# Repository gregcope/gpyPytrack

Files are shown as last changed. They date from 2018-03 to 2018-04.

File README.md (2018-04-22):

gpyPytrack
=========

Intro
==========
Based on a Pycom gpy (Bluetooth, WLAN, LTE) ESP32 MicroPython board and its associated Pytrack module that has a L76 GNSS module (and LIPO battery charger).  This project needs a Daughter board.

Aim
==========
* Be very, very low power (17uA when asleep with GNSS VBACKUP powered)
* Chargeable from 12-24V
* Rechargeable LIPO battery for easy parts sourcing
* Has a button to enable user wake up
* GNSS For location
* LTE for Coms
* BilgeSwitch and Temp (DS18B20) Alarms
* LED for Status (in switch)

Checks
=============
* Frequent
  * BilgeSwitch state
  * Temp above / below threshold
  * If in Alarm, send coms
* Less Frequent (less likely to change frequently)
  * Position
  * Battery volts
  * VCC volts
  * If in Alarm, send coms
* Daily
  * All of the above and sends status

Parts
==========
* [Pycom Gpy](https://pycom.io/hardware/gpy-specs)
* [Pycom pytrack](https://pycom.io/hardware/pytrack-specs/)
* [Mini Step Down Regulator Voltag Power Supply Module 4.5v~55v to 5v](https://www.ebay.co.uk/sch/i.html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)
* [DS18B20 Waterproof Digital Probe Temperature Sensor with Silicone Cable (higher temp) Thermometer](https://www.ebay.co.uk/sch/i.html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)
* [12V 12mm LED Power Push Button Switch Momentary Waterproof Metal 4 Pin](https://www.ebay.co.uk/sch/i.html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)
* 1200mah LIPO Battery
* Bilge Switch (any normally closed, simple switch would do)

Daughter board
==============
The Daughter board fits between the Gpy/Fipy and Pytrack module via headers (see pictures when I add them).  It is designed to hold certain parts and expose some pins via headers or JST connectors.   Its footprint is similar to the Pytrack to keep space requirements down.

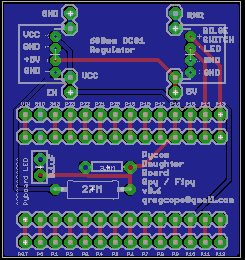
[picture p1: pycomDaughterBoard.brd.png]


The Daughter board mounts;
* VCC voltagedivider connected to an ADC pin to measure VCC
* Switchable Regulator with ENABLE pin connected to a pin
* JST(s) to breakout the relevant connections for the 11-36v VCC+GND, LED, Switch, DS18B20 Temp module, BilgeSwitch, 5V+GND for the Pytrack USB port
* __Note we will be putting 2x5pin XH JSTs on the Pytrack External IO to use those as well (simplifies this board and makes it smaller)__  

See the eagle files for the details.

Referances
=============
* https://blog.yavilevich.com/2017/03/efficient-dc-12v-to-5v-conversion-for-low-power-electronics-evaluation-of-six-modules/

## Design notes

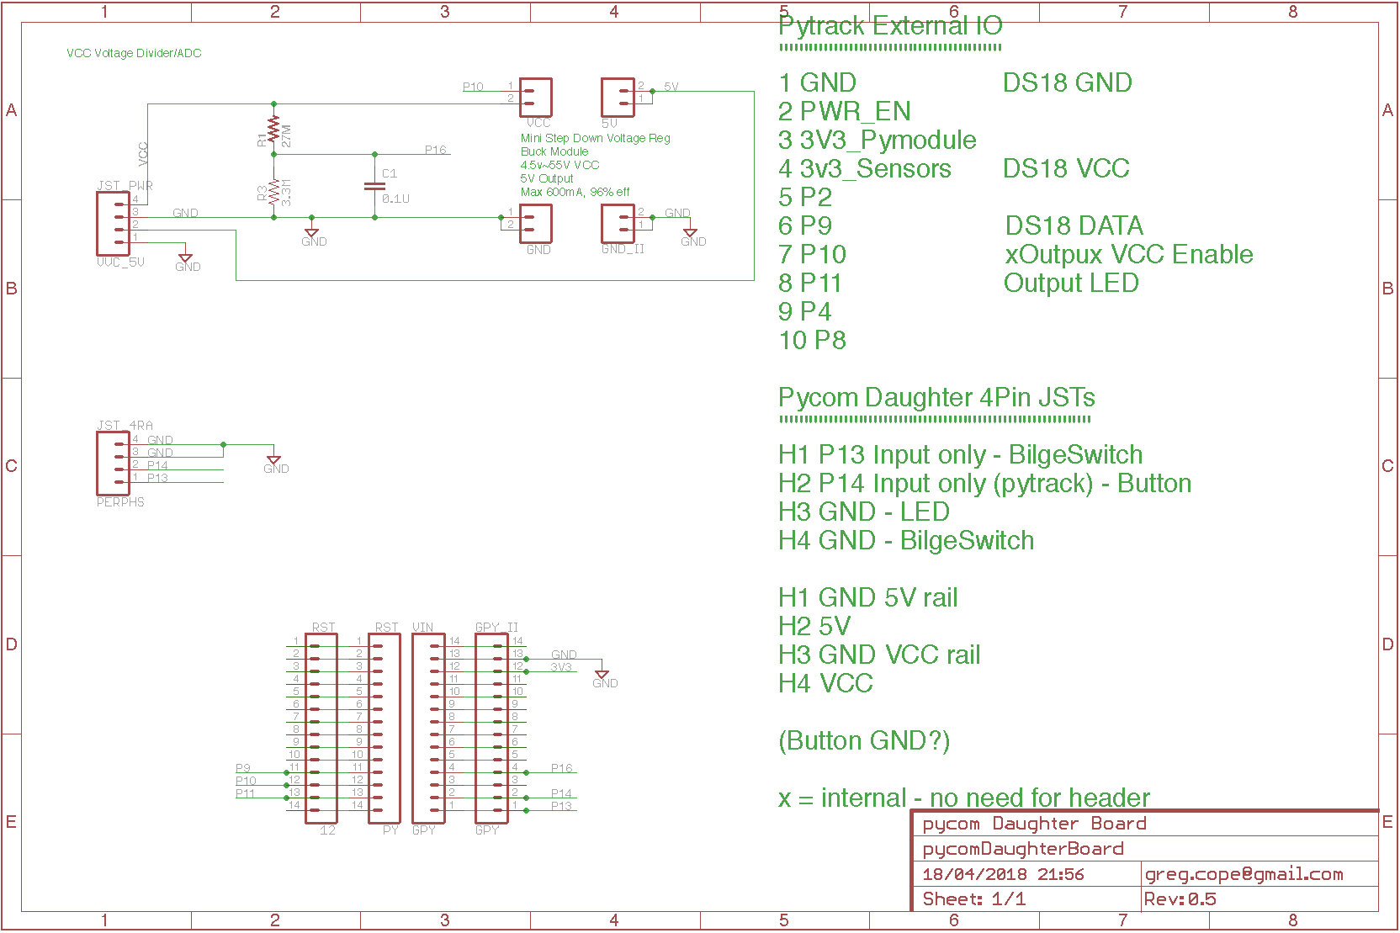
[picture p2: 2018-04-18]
pycomDaughterBoard.sch.png

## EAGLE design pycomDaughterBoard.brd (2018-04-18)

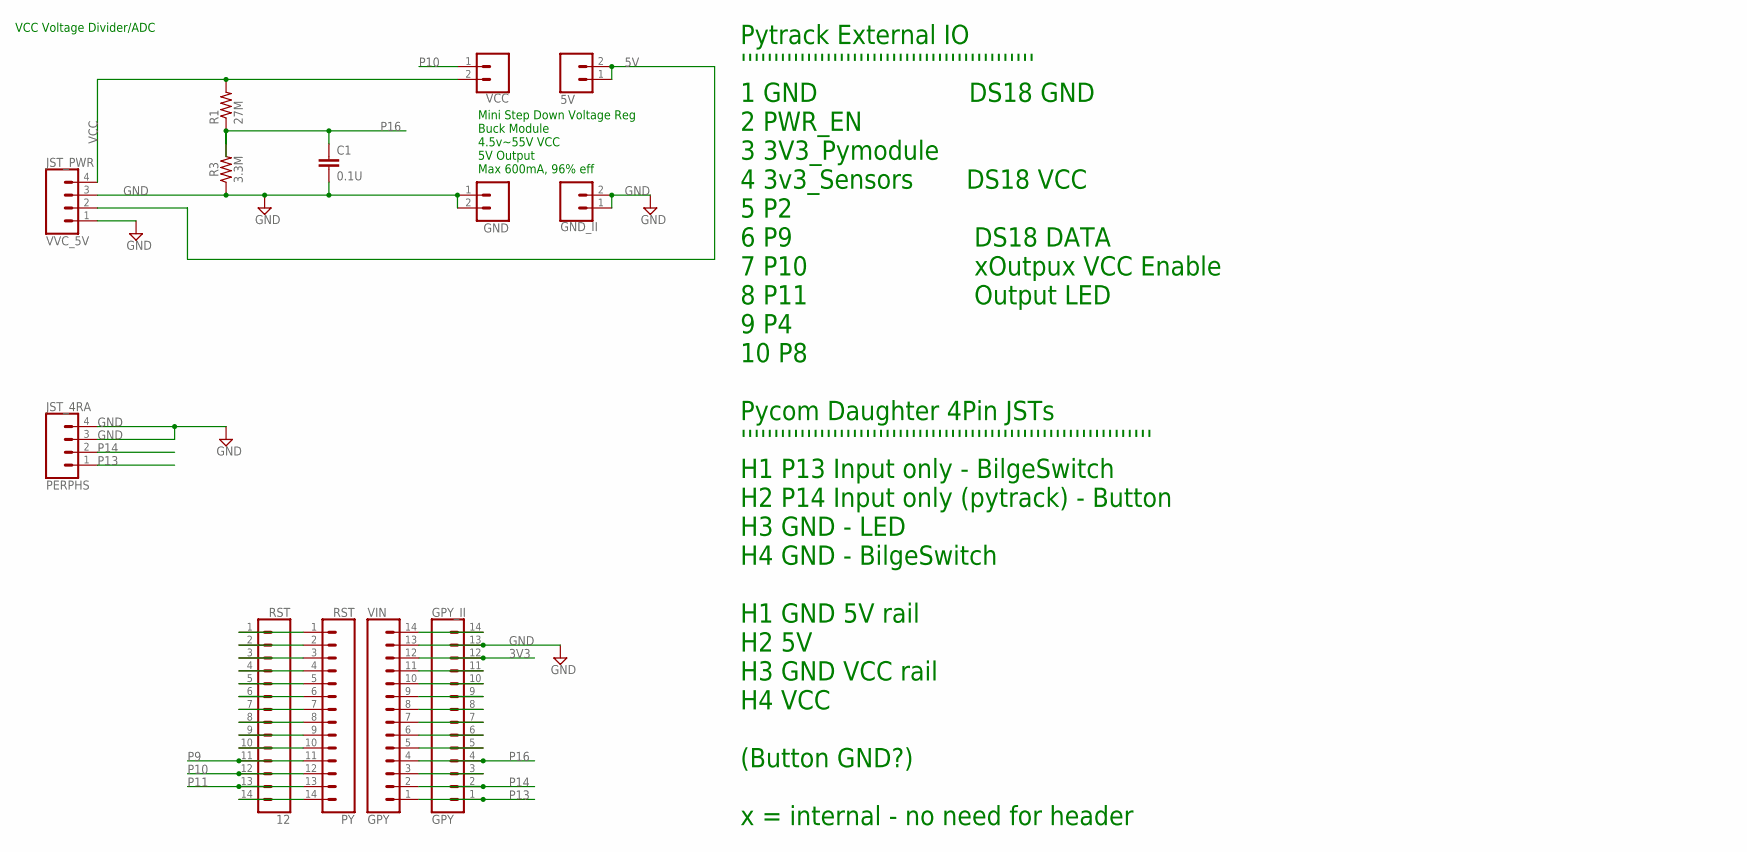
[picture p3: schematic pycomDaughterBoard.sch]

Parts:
5V: 5V; 1X02
12: RST; 1X14
C1: 0.1U; CAP-PTH-SMALL-KIT
GND: GND; 1X02
GND_II: GND; 1X02
GPY_II: GPY; 1X14
JST_4RA: PERPHS; JST-4-PTH
JST_PWR: VVC_5V; JST-4-PTH
PY: RST; 1X14
R1: 27M; 0309/12
R3: 3.3M; AXIAL-0.3
VCC: VCC; 1X02
VIN: GPY; 1X14

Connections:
3V3: GPY_II.12, VIN.12
5V: 5V.1, 5V.2, JST_PWR.2
GND: C1.2, GND.1, GND.2, GND_II.1, GND_II.2, GPY_II.13, JST_4RA.3, JST_4RA.4, JST_PWR.1, JST_PWR.3, R3.P$1 (1), VIN.13
unnamed: 12.1, PY.1
unnamed: 12.2, PY.2
unnamed: 12.3, PY.3
unnamed: 12.4, PY.4
unnamed: 12.5, PY.5
unnamed: 12.6, PY.6
unnamed: 12.7, PY.7
unnamed: 12.8, PY.8
unnamed: 12.9, PY.9
unnamed: GPY_II.14, VIN.14
unnamed: GPY_II.9, VIN.9
unnamed: 12.10, PY.10
unnamed: GPY_II.11, VIN.11
unnamed: GPY_II.10, VIN.10
unnamed: 12.14, PY.14
unnamed: GPY_II.8, VIN.8
unnamed: GPY_II.7, VIN.7
unnamed: GPY_II.3, VIN.3
P9: 12.11, PY.11
P10: 12.12, PY.12, VCC.1
P11: 12.13, PY.13
P13: GPY_II.1, JST_4RA.1, VIN.1
P14: GPY_II.2, JST_4RA.2, VIN.2
P16: C1.1, GPY_II.4, R1.1, R3.P$2 (2), VIN.4
P17: GPY_II.5, VIN.5
P18: GPY_II.6, VIN.6
VCC: JST_PWR.4, R1.2, VCC.2

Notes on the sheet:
VCC Voltage Divider/ADC
Mini Step Down Voltage Reg Buck Module 4.5v~55V VCC 5V Output Max 600mA, 96% eff
Pytrack External IO ''''''''''''''''''''''''''''''''''''''''''''' 1 GND DS18 GND 2 PWR_EN 3 3V3_Pymodule 4 3v3_Sensors DS18 VCC 5 P2 6 P9 DS18 DATA 7 P10 xOutpux VCC Enable 8 P11 Output LED 9 P4 10 P8 Pycom Daughter 4Pin JSTs ''''''''''''''''''''''''''''''''''''''''''''''''''''''''''''''' H1 P13 In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

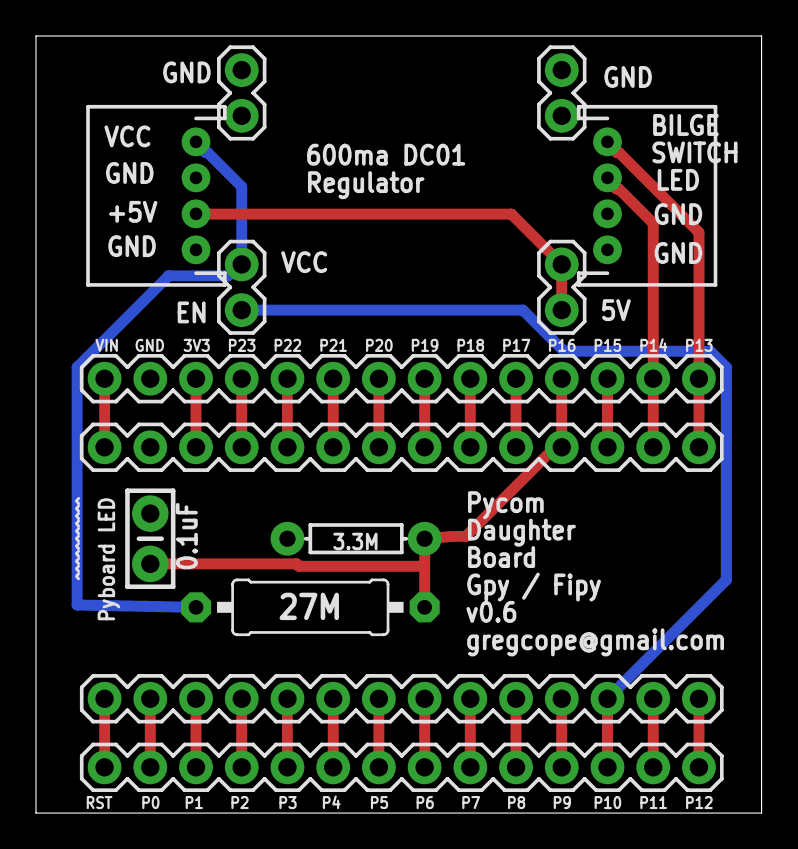
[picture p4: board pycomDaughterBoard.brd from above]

Board: 2 copper layers, 40.3 x 43.2 mm, 13 parts (0 on the bottom side), 30 nets.

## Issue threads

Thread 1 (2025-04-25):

100% compatible alternative for the GPy

daanpape, 2025-04-25:
Hi,

As the Pycom GPy that is used in this repository is now EOL, I thought it might be interesting to let you know about a 100% pin compatible module which is also a big upgrade: Walter (https://www.quickspot.io).

Walter's main updates are:

- ESP32-S3
- Newer Monarch 2 modem
- GNSS receiver built-in
- Only 9.5uA deep sleep
- Reset line to the modem
- USB-C connector for direct programming
- 3.3V output is software controlled
- All pins available to the application

gregcope, 2025-04-25:
Thanks for that - I was not aware.   I had given up on Pytrack as the support seemed to have lapsed.

I will have a look - esp interested in the 9.5uA sleep mode (and state retention on the ESP32 during that sleep).

Thanks again.

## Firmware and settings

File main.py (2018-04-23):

## Test code for read date/time from gps and update RTC
#import machine
import math
import network
#import os
import time
import utime
from machine import RTC
from machine import SD
from machine import Timer
from L76GNSS import L76GNSS
from pytrack import Pytrack
import struct
from battery import Battery
from checks import Checks
from button import Button
from vin import Vin
from bilgeSwitch import BilgeSwitch
from led import Led
from temp import Temp
from stateMachine import StateMachine
import gc

# enable GC
gc.enable()


print('Going to kipp 4 secs in 1 sec')
time.sleep(1)
py.setup_sleep(4)
print('Kip...')
py.go_to_sleep(gps=True)


# setup as a station


#battery.volts()
#print("Battery volts: {0:.2f}v".format(battery.volts()))
#if battery.alarm():
#    print('Battery Needs a charge')
#else:
#    print('Battery okay')

# roughly works ...
vin = Vin('P16', 'P10')
led = Led('P11')
battery = Battery(py)

# still need work
stateMachine = StateMachine()
bilgeSwitch = BilgeSwitch('P13')
temp = Temp('P9')
button = Button('P14')

check = Checks(led, vin, bilgeSwitch, battery, temp, stateMachine)
check.whichToDo()

# https://forum.pycom.io/topic/1626/pytrack-gps-api/12

# to sleep with GPS VBACKUP on
# should go down to 17ua
# https://forum.pycom.io/topic/2525/power-consumption/16
#
# py.go_to_sleep(True)


# tell us why we woke
# display the reset reason code and the sleep remaining in seconds
# possible values of wakeup reason are:
# WAKE_REASON_ACCELEROMETER = 1
# WAKE_REASON_PUSH_BUTTON = 2
# WAKE_REASON_TIMER = 4
# WAKE_REASON_INT_PIN = 8

print("Wakeup reason: " + str(py.get_wake_reason()))
if py.get_wake_reason():
    print("Approximate sleep remaining: " + str(py.get_sleep_remaining()) + " sec")

# enable wakeup source from INT pin
py.setup_int_pin_wake_up(False)

# enable activity and also inactivity interrupts, using the default callback handler
py.setup_int_wake_up(True, True)

#Start GPS
#py = Pytrack()
l76 = L76GNSS(py, timeout=600)
#start rtc
rtc = machine.RTC()
start = utime.ticks_ms()
print('Aquiring GPS signal ', end='')
#try to get gps date to config rtc

while (True):
   gps_datetime = l76.get_datetime()
   coord2 = l76.get_datetime()
   print("$G_RMC>> {} - Free Mem: {}".format(coord2, gc.mem_free()))
   #print('.', end='')
   #case valid readings
   if gps_datetime[3]:
       print(' done')
       end = utime.ticks_ms()
       took = end - start
       print("First GNS fix took: {} mSec".format(took))

       day = int(gps_datetime[4][0] + gps_datetime[4][1] )
       month = int(gps_datetime[4][2] + gps_datetime[4][3] )
       year = int('20' + gps_datetime[4][4] + gps_datetime[4][5] )
       hour = int(gps_datetime[2][0] + gps_datetime[2][1] )
       minute = int(gps_datetime[2][2] + gps_datetime[2][3] )
       second = int(gps_datetime[2][4] + gps_datetime[2][5] )
       print("Current location: {}  {} ; Date: {}/{}/{} ; Time: {}:{}:{}".format(gps_datetime[0],gps_datetime[1], day, month, year, hour, minute, second))
       rtc.init( (year, month, day, hour, minute, second, 0, 0))
       break

print('RTC Set from GPS to UTC:', rtc.now())

chrono = Timer.Chrono()
chrono.start()

print("RTC time : {}".format(rtc.now()))
   #coord = l76.coordinates()
   # lat_d, lon_d
   #print("$GPGLL>> {} - Free Mem: {}".format(coord, gc.mem_free()))
coord1 = l76.coordinates1()
# lat_d, lon_d, gps_time, gps_altitude, valid, num_satellites, hdop
print("$GPGGA>> {} - Free Mem: {}".format(coord1, gc.mem_free()))
   #coord2 = l76.get_datetime()
   # lat_d, lon_d, gps_time, valid, gps_date
   #print("$G_RMC>> {} - Free Mem: {}".format(coord2, gc.mem_free()))

# go to sleep for 60 secs maximum if no button interrupt happens
#pycom.rgbled(0x00FF00)
#time.sleep(2)


# switch off heartbeat LED
#pycom.heartbeat(False)
print('Going to kipp 2 secs in 1 sec')
time.sleep(1)
py.setup_sleep(2)
py.go_to_sleep(gps=True)

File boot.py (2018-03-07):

from machine import UART
import machine
import os
from network import WLAN
from network import Bluetooth
from network import LTE
from pytrack import Pytrack
import network
import utime
import pycom

start = utime.ticks_us()
uart = UART(0, baudrate=115200)
os.dupterm(uart)

# switch stuff off ...
# WLAN off
wlan = WLAN()
#wlan.init(mode=WLAN.STA)
wlan.deinit()
# Bluetooth off
#bt = Bluetooth()
#bt.deinit()
# LTE off
#lte = LTE()
#lte.disconnect()
#lte.deinit()
# switch off FTP and telnet servers
server = network.Server()
server.deinit()
# done switching stuff off

# Initialise some other objects
py = Pytrack()

machine.main('main.py')

end = utime.ticks_us()
took = end - start
print("boot.py ... done in: {} uSec".format(took))
utime.sleep(2)

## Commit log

2018-03-04 added eagle v0.1 boards
    [pycomDaughterBoard.brd, pycomDaughterBoard.sch]
2018-03-05 adding board images
2018-03-05 added battery class
2018-03-05 Battery logic tested
2018-03-06 Initial comit - boiler plate - does not actually work
2018-03-07 checks framework for bilgeSwitch
2018-03-14 Case changes
2018-03-15 pin doco
2018-03-16 removed power pin as we are going to use 3V3_SENSORS on the pytrack
2018-03-16 changes to pin outs.
2018-03-17 debug print
2018-03-30 new v0.3 board
2018-03-30 Corrections / labels
    [pycomDaughterBoard.brd]
2018-03-30 Added 5v
    [pycomDaughterBoard.brd]
2018-03-30 Moved vias
    [pycomDaughterBoard.brd]
2018-03-30 Aligned Pins with real board
2018-03-30 Text update, move VCC connector
    [pycomDaughterBoard.brd]
2018-03-30 text update
    [pycomDaughterBoard.brd]
2018-03-30 Setup Voltage divider and reg enable pin
2018-03-30 switch led on / off
2018-03-30 switch objects round into list of might work vs still need some work
2018-03-31 Battery class looks like it should work, needs testing.
2018-03-31 Info on Daughter board + typos.
2018-03-31 v0.4 of board, with JSR headers
    [pycomDaughterBoard.brd, pycomDaughterBoard.sch]
2018-04-18 Board v0.6 updates
    [pycomDaughterBoard.brd, pycomDaughterBoard.sch]
2018-04-18 updates to board layout/silkscreen 0.6v
    [pycomDaughterBoard.brd]
2018-04-22 added some threading ideas
2018-04-23 Temp threading

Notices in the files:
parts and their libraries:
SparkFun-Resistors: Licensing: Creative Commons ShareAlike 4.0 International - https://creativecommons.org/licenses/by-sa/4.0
